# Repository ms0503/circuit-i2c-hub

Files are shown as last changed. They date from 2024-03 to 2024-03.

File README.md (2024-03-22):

レベル変換付きI²Cハブ
=============

レベル変換付きI²Cハブはプルアップ切り替え機能、
スレーブ側の信号レベル・供給電圧を3.3V・5Vから選択する機能を備えた5口I²Cハブです。
基本的にマスター側からの5V供給で動きますが外部電源からの供給も可能です。

# インターフェース
## マスター
電源ラインは5V固定、信号レベルは3.3V固定です。外部電源未接続時の電源供給も兼務しています。
横のスイッチでプルアップの切り替えを行うことができます。

## スレーブ
電源ライン・信号レベルは3.3V・5Vから選択でき、横のスイッチでプルアップの切り替えを行うことができます。
4つ搭載されています。

# ライブラリ
この基板は一部のシンボル・フットプリントに[kicad-mecha](https://github.com/ms0503/kicad-mecha.git)を使用しています。
別途インポートした上でご利用下さい。

# 設計者
Sora Tonami <[ms0503@outlook.com](mailto:ms0503@outlook.com)>

# ライセンス
この基板のデータは[MITライセンス](LICENSE.md)の下に公開されます。ご自由に改変・再配布して頂いて構いません。

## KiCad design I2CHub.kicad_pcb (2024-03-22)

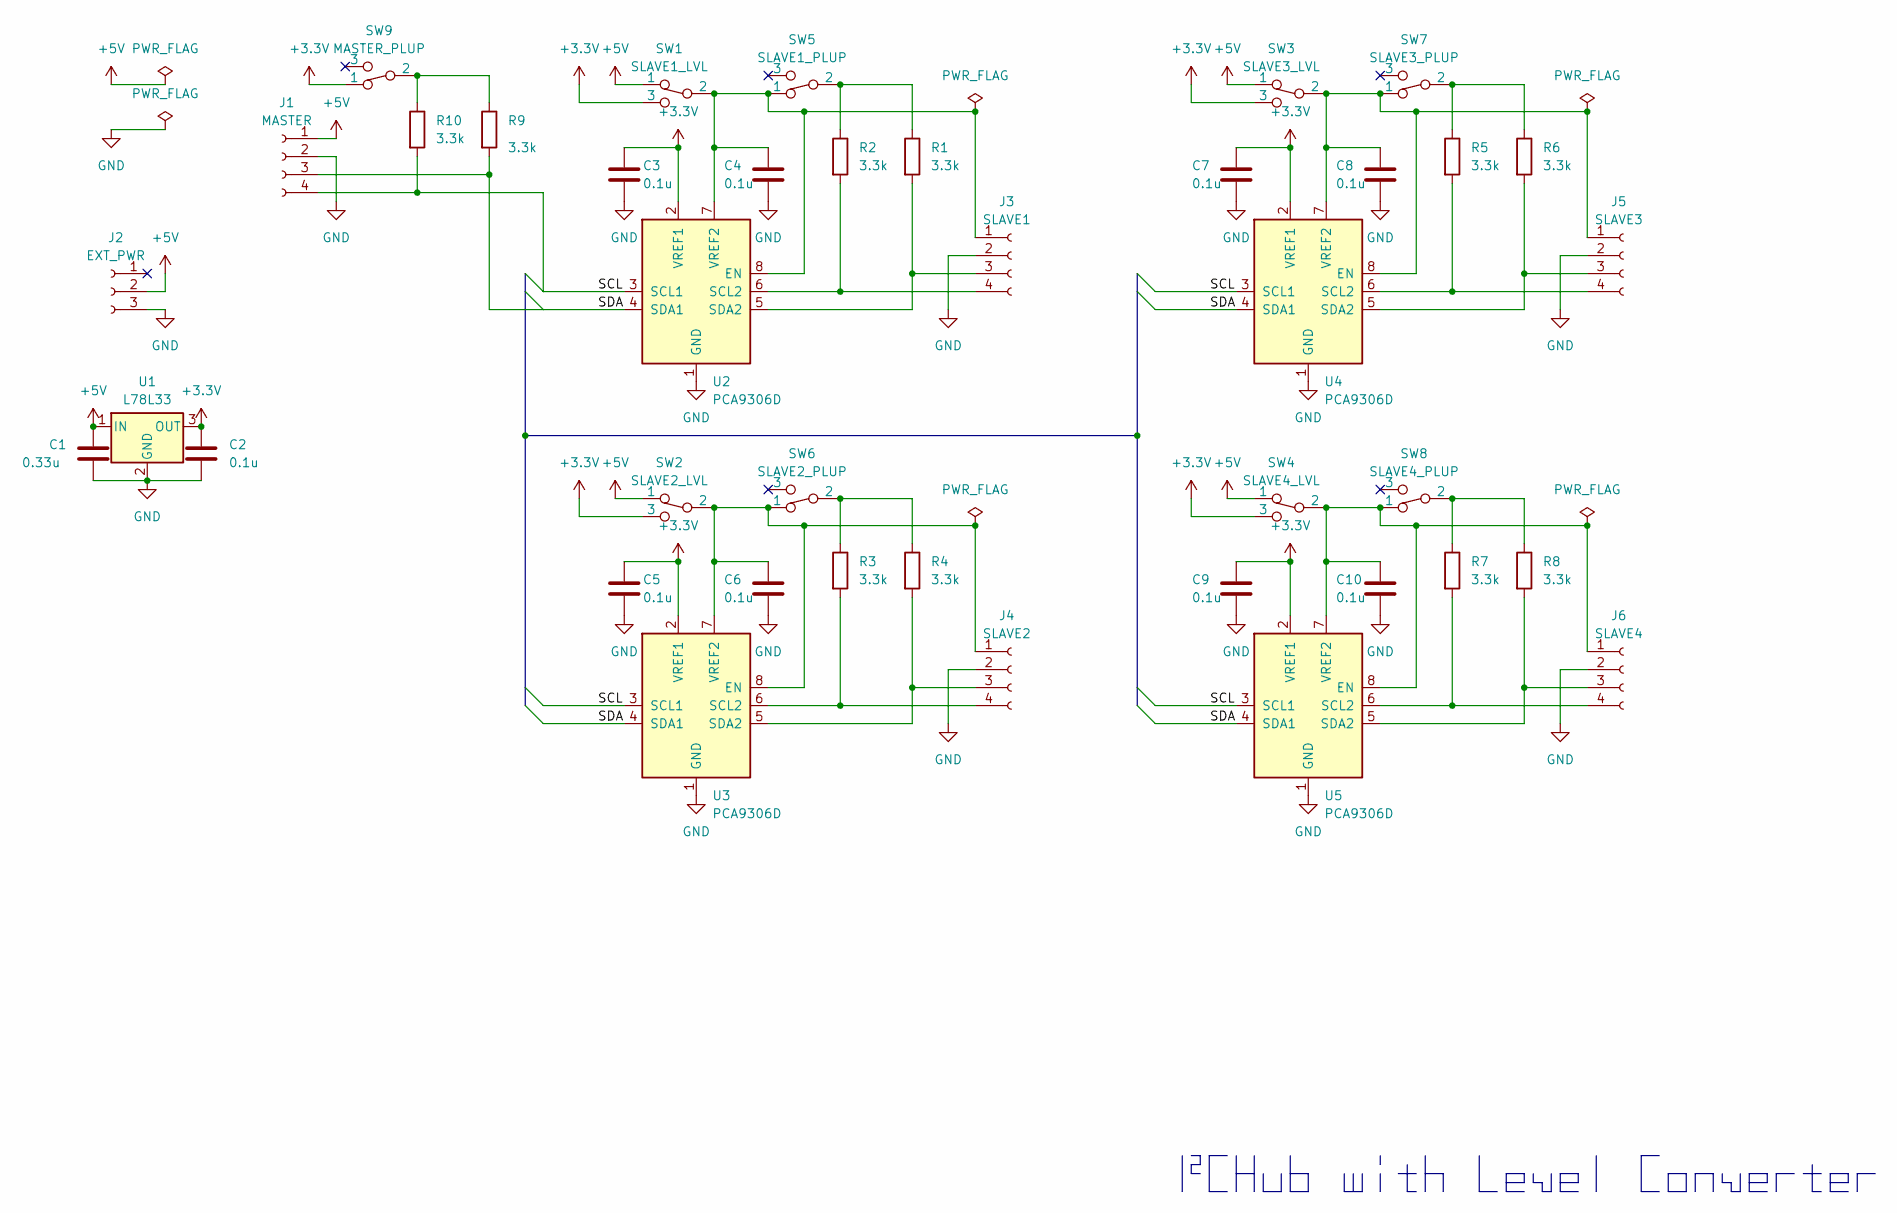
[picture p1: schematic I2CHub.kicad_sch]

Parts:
C1: 0.33u; C_0805_2012Metric
C2, C3, C4, C5, C6, C7, C8, C9, C10: 0.1u; C_0805_2012Metric
J1: MASTER; XA_4pin_Straight
J2: EXT_PWR; JST_XH_B3B-XH-A_1x03_P2.50mm_Vertical
J3: SLAVE1; XA_4pin_Straight
J4: SLAVE2; XA_4pin_Straight
J5: SLAVE3; XA_4pin_Straight
J6: SLAVE4; XA_4pin_Straight
R1, R2, R3, R4, R5, R6, R7, R8, R9, R10: 3.3k; R_0603_1608Metric
SW1: SLAVE1_LVL; toggle_1-2
SW2: SLAVE2_LVL; toggle_1-2
SW3: SLAVE3_LVL; toggle_1-2
SW4: SLAVE4_LVL; toggle_1-2
SW5: SLAVE1_PLUP; toggle_1-2
SW6: SLAVE2_PLUP; toggle_1-2
SW7: SLAVE3_PLUP; toggle_1-2
SW8: SLAVE4_PLUP; toggle_1-2
SW9: MASTER_PLUP; toggle_1-2
U1: L78L33; SOT-89-3
U2, U3, U4, U5: PCA9306D; SO-8_3.9x4.9mm_P1.27mm

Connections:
+3.3V: C2.1, C3.1, C5.1, C7.1, C9.1, SW1.3, SW2.3, SW3.3, SW4.3, SW9.1, U1.3 (OUT), U2.2 (VREF1), U3.2 (VREF1), U4.2 (VREF1), U5.2 (VREF1)
+5V: C1.1, J1.1, J2.2, SW1.1, SW2.1, SW3.1, SW4.1, U1.1 (IN)
/SCL: J1.4, R10.2, U2.3 (SCL1), U3.3 (SCL1), U4.3 (SCL1), U5.3 (SCL1)
/SDA: J1.3, R9.2, U2.4 (SDA1), U3.4 (SDA1), U4.4 (SDA1), U5.4 (SDA1)
GND: C1.2, C2.2, C3.2, C4.2, C5.2, C6.2, C7.2, C8.2, C9.2, C10.2, J1.2, J2.3, J3.2, J4.2, J5.2, J6.2, U1.2 (GND), U2.1 (GND), U3.1 (GND), U4.1 (GND), U5.1 (GND)
unnamed: C4.1, J3.1, SW1.2, SW5.1, U2.7 (VREF2), U2.8 (EN)
unnamed: J3.3, R1.2, U2.5 (SDA2)
unnamed: J3.4, R2.2, U2.6 (SCL2)
unnamed: C6.1, J4.1, SW2.2, SW6.1, U3.7 (VREF2), U3.8 (EN)
unnamed: J4.3, R4.2, U3.5 (SDA2)
unnamed: J4.4, R3.2, U3.6 (SCL2)
unnamed: C8.1, J5.1, SW3.2, SW7.1, U4.7 (VREF2), U4.8 (EN)
unnamed: J5.3, R6.2, U4.5 (SDA2)
unnamed: J5.4, R5.2, U4.6 (SCL2)
unnamed: C10.1, J6.1, SW4.2, SW8.1, U5.7 (VREF2), U5.8 (EN)
unnamed: J6.3, R8.2, U5.5 (SDA2)
unnamed: J6.4, R7.2, U5.6 (SCL2)
unnamed: R1.1, R2.1, SW5.2
unnamed: R3.1, R4.1, SW6.2
unnamed: R5.1, R6.1, SW7.2
unnamed: R7.1, R8.1, SW8.2
unnamed: R9.1, R10.1, SW9.2

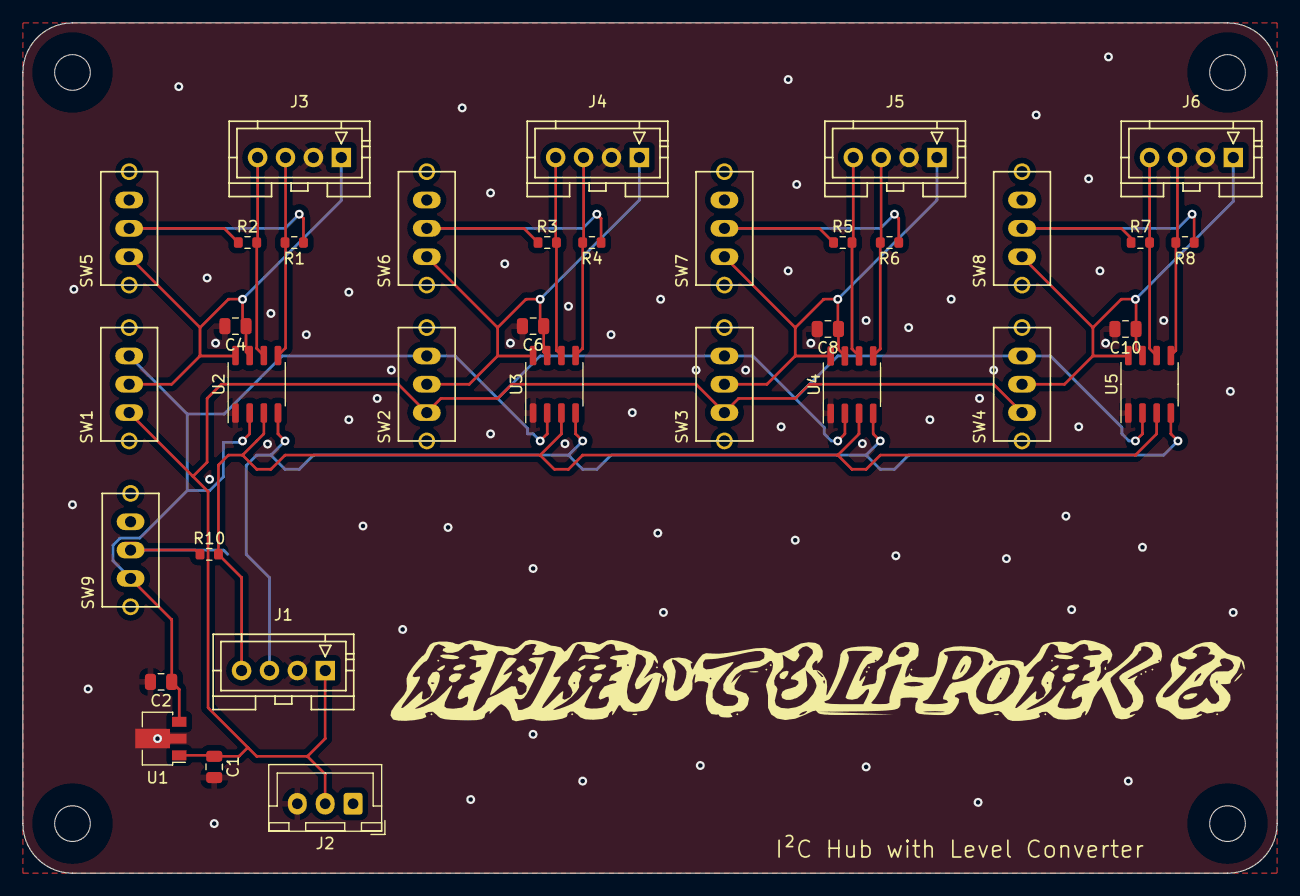
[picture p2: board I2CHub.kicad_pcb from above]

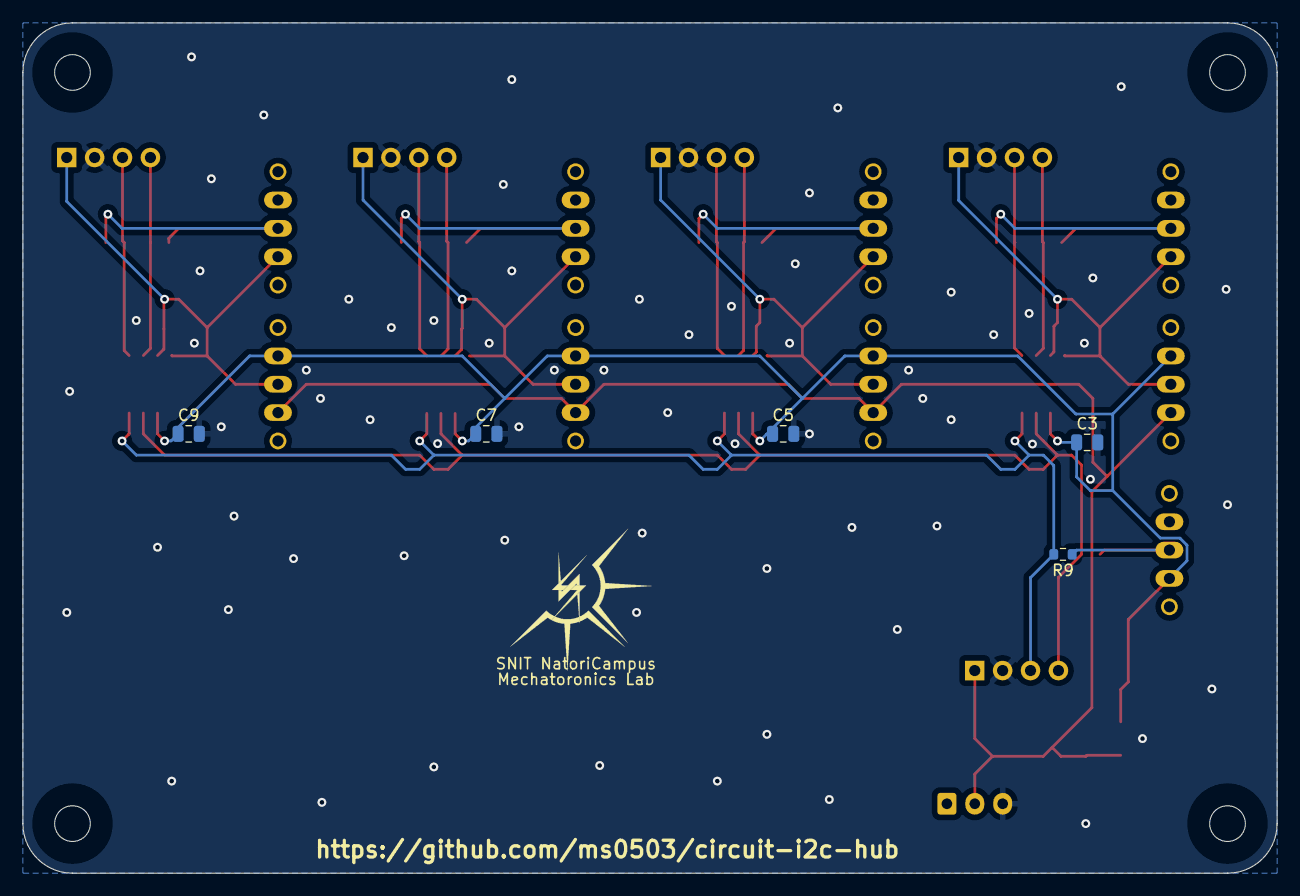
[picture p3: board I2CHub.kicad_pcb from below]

Board: 2 copper layers, 112.4 x 76.2 mm, 44 parts (5 on the bottom side), 22 nets.

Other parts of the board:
 : holeφ3.2
 #2,  #3,  #4: holeφ3.2
